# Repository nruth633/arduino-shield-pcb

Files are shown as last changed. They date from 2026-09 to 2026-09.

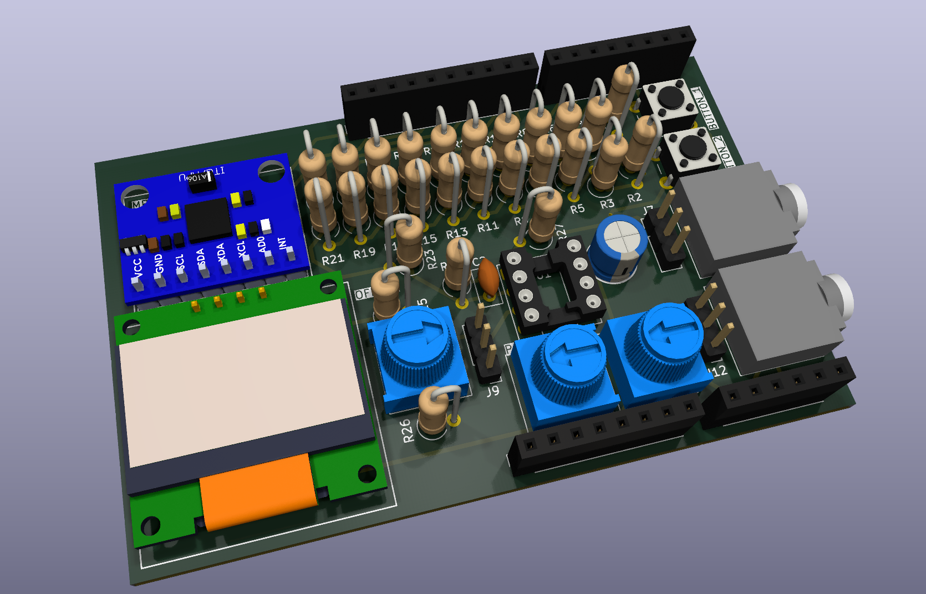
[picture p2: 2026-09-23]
UNO_shield_1/docs/PCB_3D.png

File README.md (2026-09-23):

# Arduino Uno I/O Shield

An Arduino Uno shield I designed in KiCad, had fabricated, and soldered by hand. It adds a
10-bit R-2R ladder DAC (10 kΩ / 20 kΩ, on D0–D9) buffered by an MCP6002 op-amp, 3.5 mm
audio in and out jacks, two pots, two buttons, and headers for an MPU6050 IMU and an
SSD1306 OLED.

Write-up: https://nruth633.github.io/projects/io-shield.html

The KiCad project is in `UNO_shield_1/` (open `ShieldV1.kicad_pro` in KiCad 9 or newer),
along with the gerbers and BOM.

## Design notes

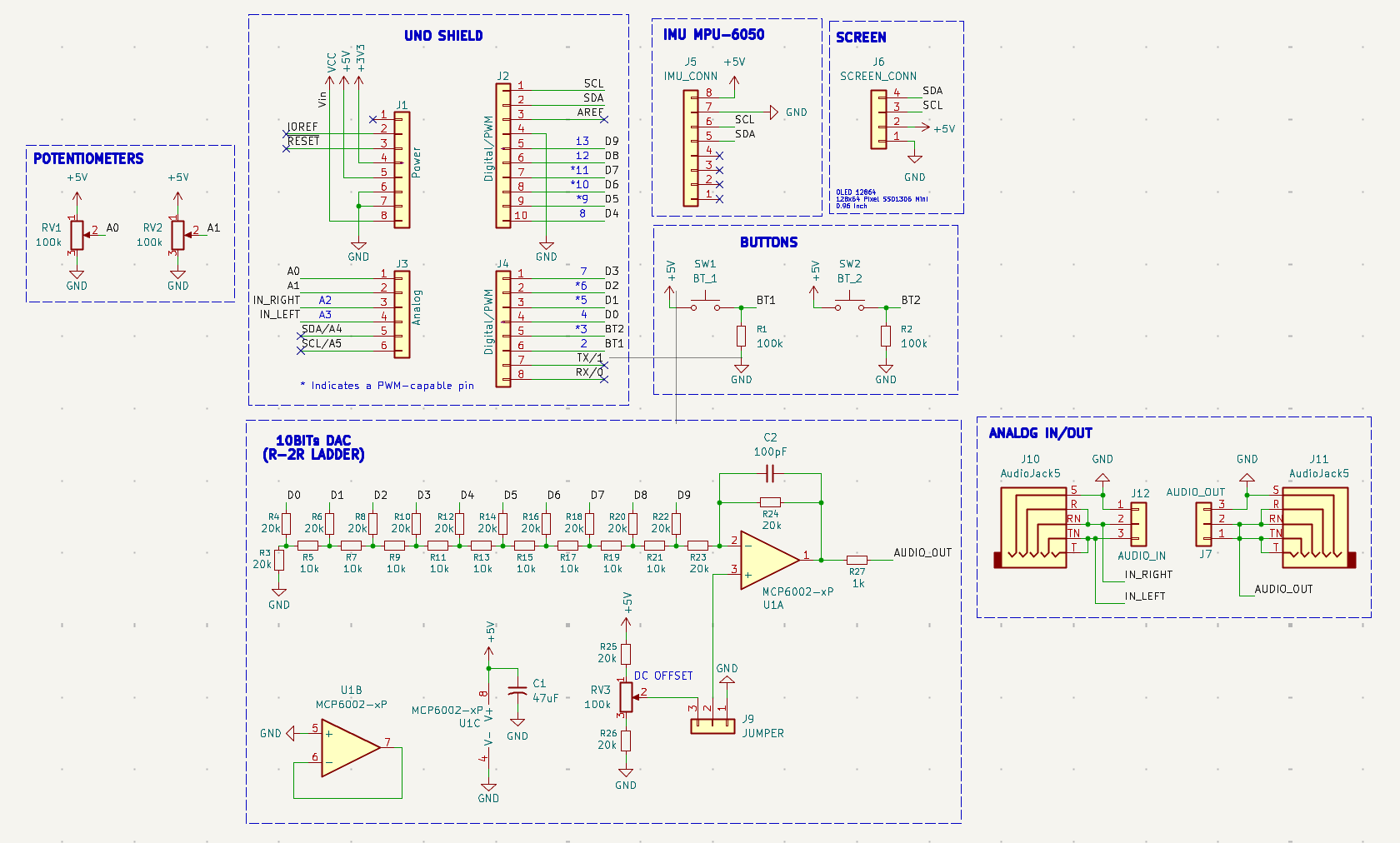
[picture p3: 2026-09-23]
UNO_shield_1/docs/PCB_schematic.png

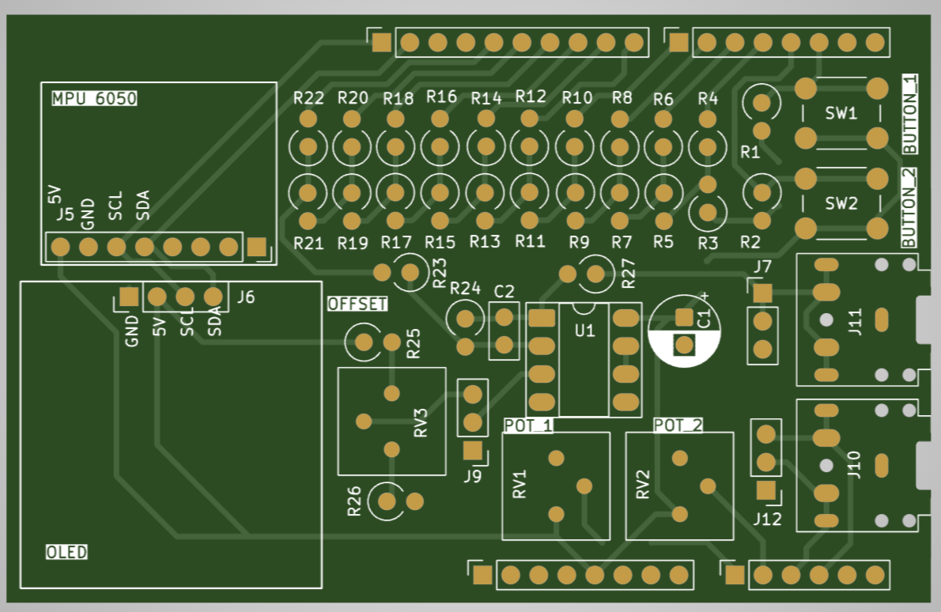
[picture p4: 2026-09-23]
UNO_shield_1/docs/PCB_front.png

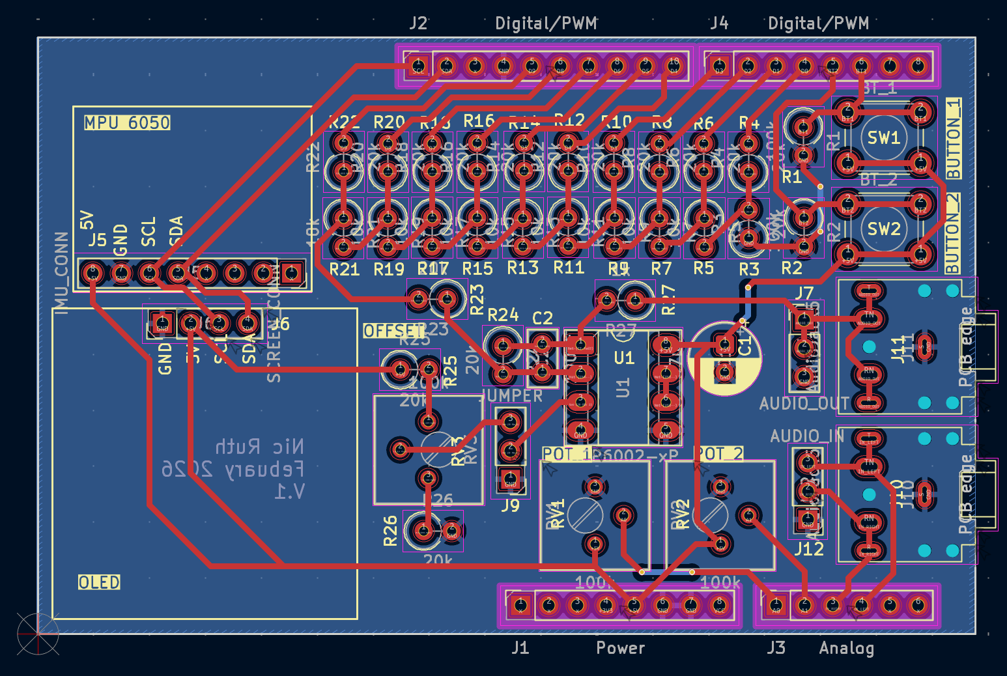
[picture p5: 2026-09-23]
UNO_shield_1/docs/PCB_layout.png

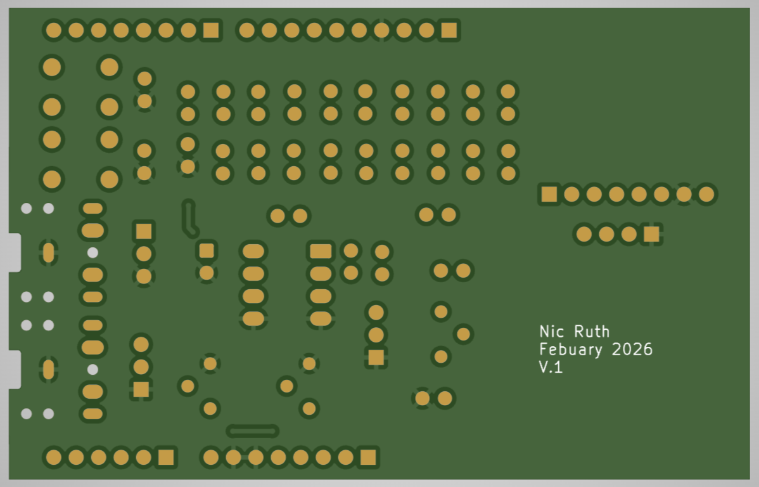
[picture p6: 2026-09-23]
UNO_shield_1/docs/PCB_back.png

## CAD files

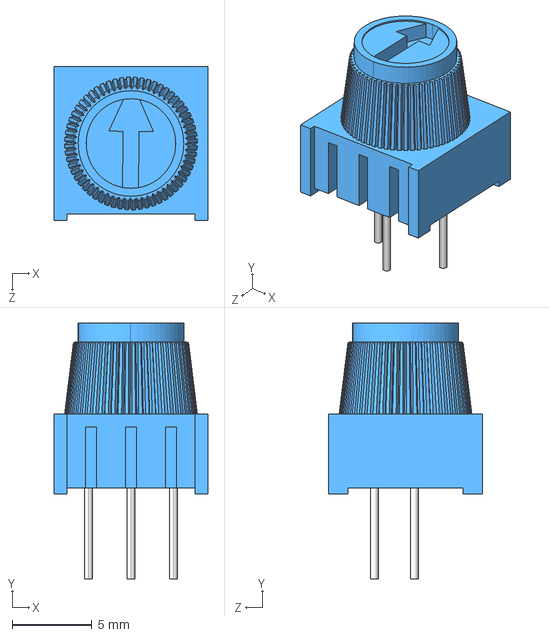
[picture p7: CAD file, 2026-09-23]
UNO_shield_1/components/10k_Trim_Pot/10 kΩ Breadboard Trim Potentiometer with Knob.STEP
9.60 x 16.0 x 9.60 mm
BASE, 10 KILO-OHM BREADBOARD TRIM POTENTIOMETER WITH KNOB
KNOB, 10 KILO-OHM BREADBOARD TRIM POTENTIOMETER WITH KNOB

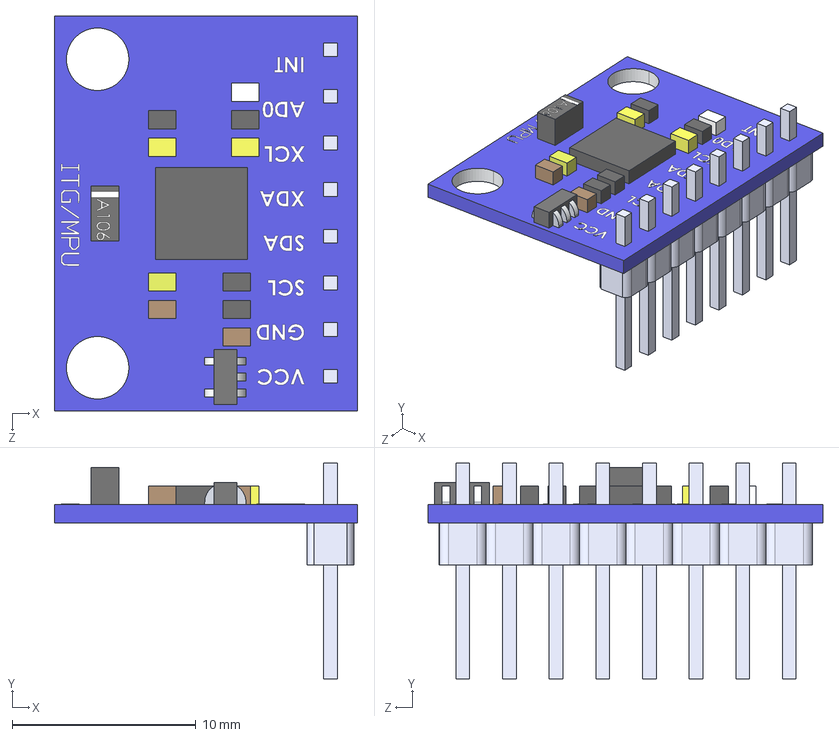
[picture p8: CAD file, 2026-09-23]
UNO_shield_1/components/MPU6050/ITG-MPU.STEP
16.5 x 11.8 x 21.5 mm
8 Header-Pin
Placa_Base

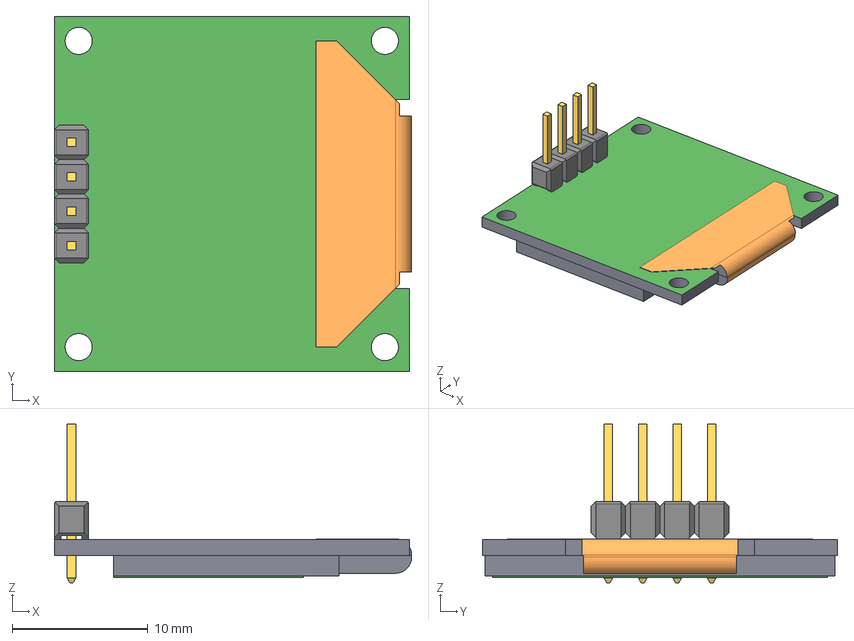
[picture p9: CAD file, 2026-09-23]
UNO_shield_1/components/OLED_096_in/OLED TEMU 0.96 in.stp
26.4 x 26.2 x 11.7 mm
brep_2 x 4

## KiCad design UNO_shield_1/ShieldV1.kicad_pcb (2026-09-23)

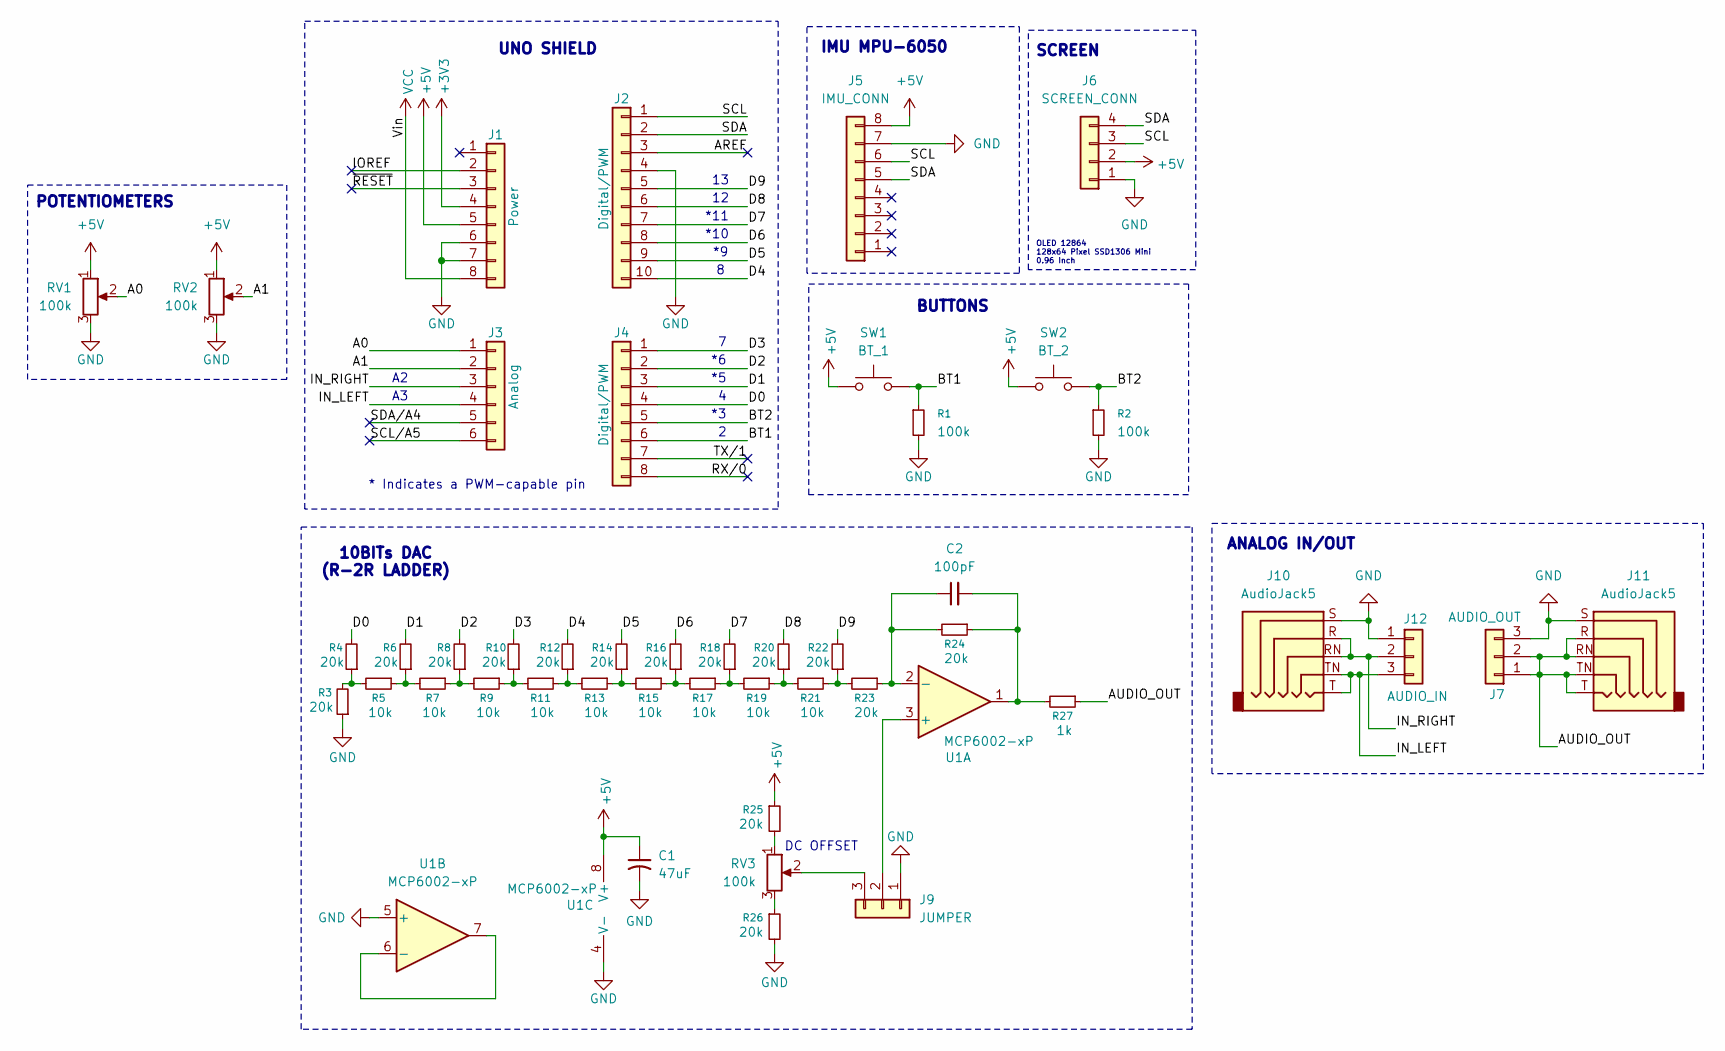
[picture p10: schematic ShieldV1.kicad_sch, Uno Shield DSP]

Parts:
C1: 47uF; CP_Radial_D8.0mm_P2.50mm
C2: 100pF; C_Disc_D5.0mm_W2.5mm_P2.50mm
J1: Power; PinSocket_1x08_P2.54mm_Vertical
J2: Digital/PWM; PinSocket_1x10_P2.54mm_Vertical
J3: Analog; PinSocket_1x06_P2.54mm_Vertical
J4: Digital/PWM; PinSocket_1x08_P2.54mm_Vertical
J5: IMU_CONN; PinSocket_1x08_P2.54mm_Vertical
J6: SCREEN_CONN; PinHeader_1x04_P2.54mm_Vertical
J7: AUDIO_OUT; PinHeader_1x03_P2.54mm_Vertical
J9: JUMPER; PinHeader_1x03_P2.54mm_Vertical
J10, J11: AudioJack5; Jack_3.5mm_CUI_SJ1-3525N_Horizontal
J12: AUDIO_IN; PinHeader_1x03_P2.54mm_Vertical
R1, R2: 100k; R_Axial_DIN0309_L9.0mm_D3.2mm_P2.54mm_Vertical
R3, R4, R6, R8, R10, R12, R14, R16, R18, R20, R22, R23, R24, R25, R26: 20k; R_Axial_DIN0309_L9.0mm_D3.2mm_P2.54mm_Vertical
R5, R7, R9, R11, R13, R15, R17, R19, R21: 10k; R_Axial_DIN0309_L9.0mm_D3.2mm_P2.54mm_Vertical
R27: 1k; R_Axial_DIN0309_L9.0mm_D3.2mm_P2.54mm_Vertical
RV1, RV2, RV3: 100k; Potentiometer_Bourns_3386P_Vertical
SW1: BT_1; SW_PUSH_6mm
SW2: BT_2; SW_PUSH_6mm
U1: MCP6002-xP; DIP-8_W7.62mm_Socket_LongPads

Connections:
+3V3: J1.4
+5V: C1.1, J1.5, J5.8, J6.2, R25.1, RV1.1, RV2.1, SW1.1, SW2.1, U1.8 (V+)
/A0: J3.1, RV1.2
/A1: J3.2, RV2.2
/AREF: J2.3
/AUDIO_OUT: J7.1, J7.2, J11.R, J11.RN, J11.T, J11.TN, R27.1
/BT1: J4.6, R1.1, SW1.2
/BT2: J4.5, R2.1, SW2.2
/D0: J4.4, R4.2
/D1: J4.3, R6.2
/D2: J4.2, R8.2
/D3: J4.1, R10.2
/D4: J2.10, R12.2
/D5: J2.9, R14.2
/D6: J2.8, R16.2
/D7: J2.7, R18.2
/D8: J2.6, R20.2
/D9: J2.5, R22.2
/IN_LEFT: J3.4, J10.T, J10.TN, J12.3
/IN_RIGHT: J3.3, J10.R, J10.RN, J12.2
/IOREF: J1.2
/RX/0: J4.8
/SCL: J2.1, J5.6, J6.3
/SCL/A5: J3.6
/SDA: J2.2, J5.5, J6.4
/SDA/A4: J3.5
/TX/1: J4.7
/~RESET: J1.3
GND: C1.2, J1.6, J1.7, J2.4, J5.7, J6.1, J7.3, J9.1, J10.S, J11.S, J12.1, R1.2, R2.2, R3.1, R26.2, RV1.3, RV2.3, U1.4 (V-), U1.5 (+)
unnamed: C2.2, R24.1, R27.2, U1.1
unnamed: J9.2, U1.3 (+)
unnamed: J9.3, RV3.2
unnamed: R3.2, R4.1, R5.2
unnamed: R5.1, R6.1, R7.2
unnamed: R7.1, R8.1, R9.2
unnamed: R9.1, R10.1, R11.2
unnamed: R11.1, R12.1, R13.2
unnamed: R13.1, R14.1, R15.2
unnamed: R15.1, R16.1, R17.2
unnamed: R17.1, R18.1, R19.2
unnamed: R19.1, R20.1, R21.2
unnamed: R21.1, R22.1, R23.2
unnamed: R25.2, RV3.1
unnamed: R26.1, RV3.3
unnamed: C2.1, R23.1, R24.2, U1.2 (-)
unnamed: U1.6 (-), U1.7
VCC: J1.8

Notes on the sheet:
BUTTONS
IMU MPU-6050
POTENTIOMETERS
*11
DC OFFSET
10BITs DAC (R-2R LADDER)
ANALOG IN/OUT
*10
OLED 12864 128x64 Pixel SSD1306 Mini 0.96 Inch
* Indicates a PWM-capable pin
SCREEN
UNO SHIELD

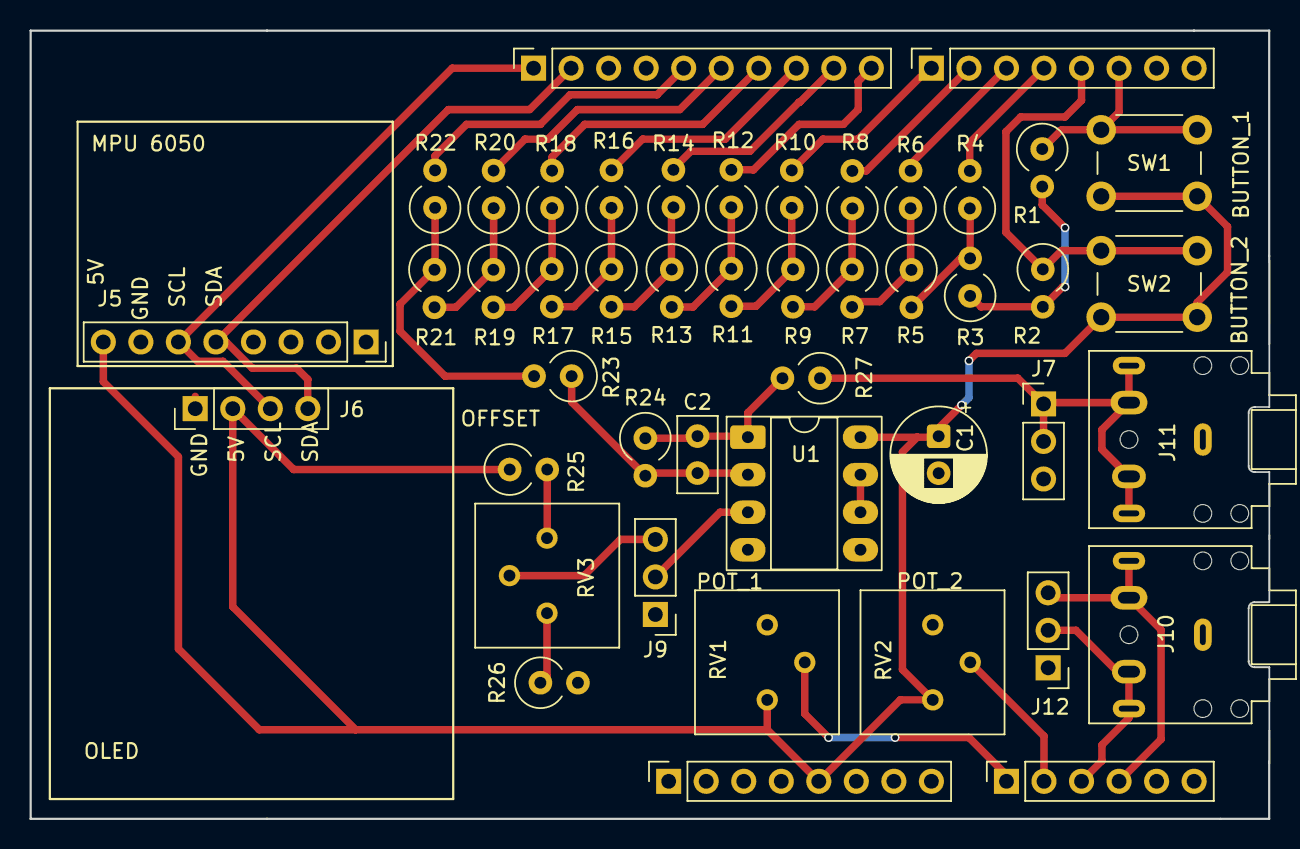
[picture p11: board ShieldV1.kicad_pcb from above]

Board: 2 copper layers, 83.8 x 53.3 mm, 46 parts (0 on the bottom side), 38 nets.
